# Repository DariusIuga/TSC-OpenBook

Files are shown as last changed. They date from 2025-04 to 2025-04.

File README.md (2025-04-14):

# TSC-OpenBook

An implementation of an open-source E-book reader made in Autodesk Fusion 360.

## Block Diagram
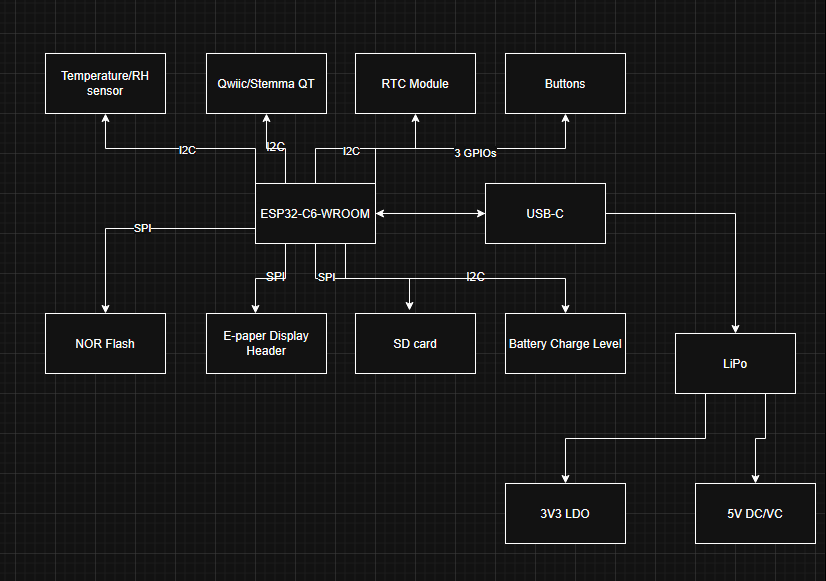
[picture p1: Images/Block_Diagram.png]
Diagram


## Enclosure
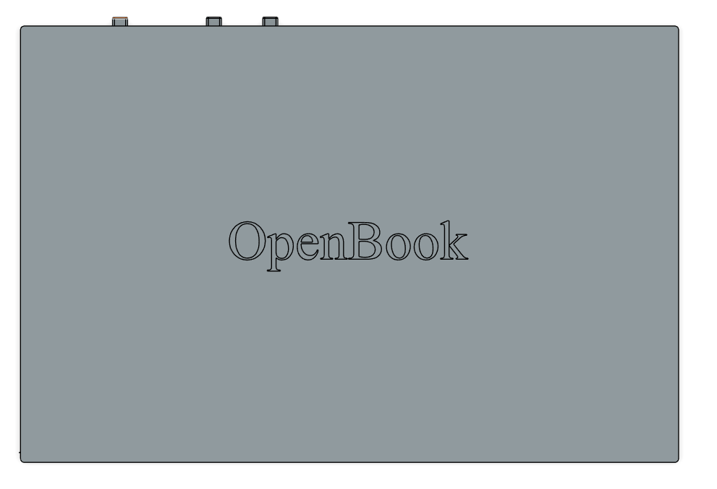
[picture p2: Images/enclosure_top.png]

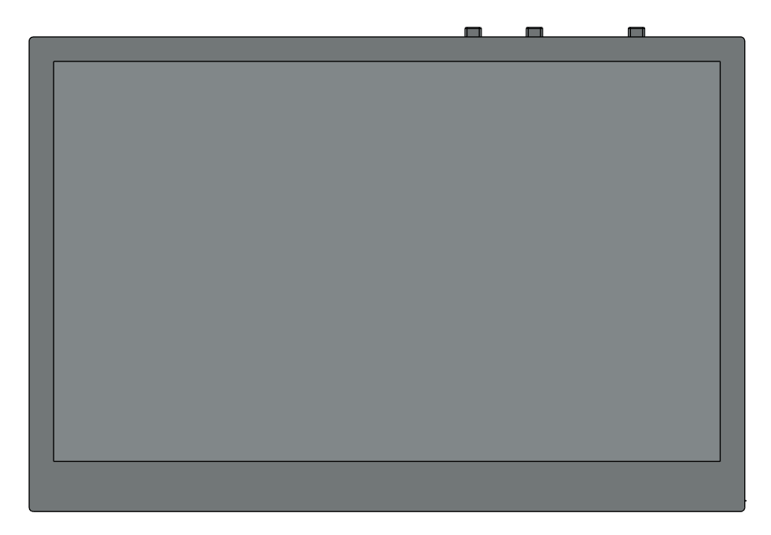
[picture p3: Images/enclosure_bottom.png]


## PCB
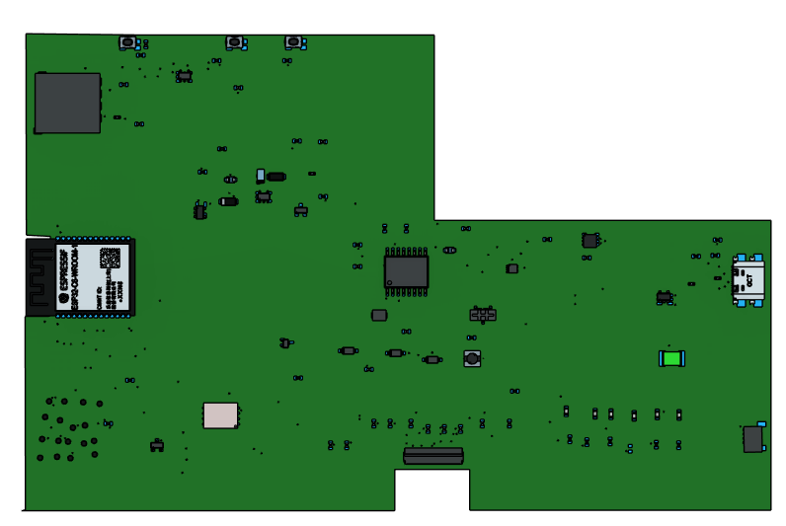
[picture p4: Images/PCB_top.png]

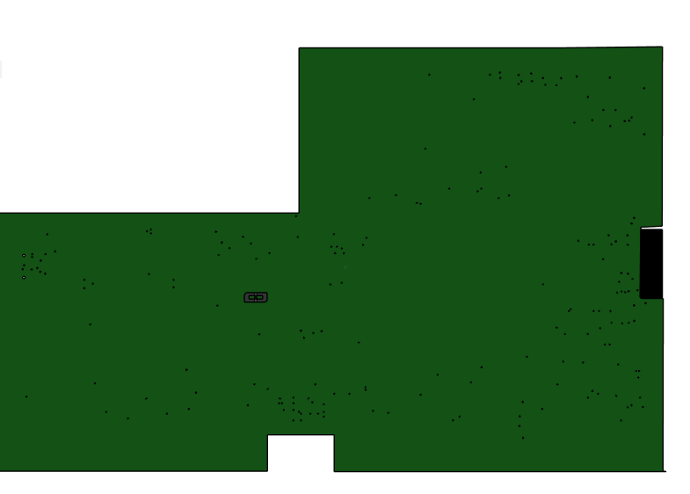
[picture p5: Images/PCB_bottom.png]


## Display

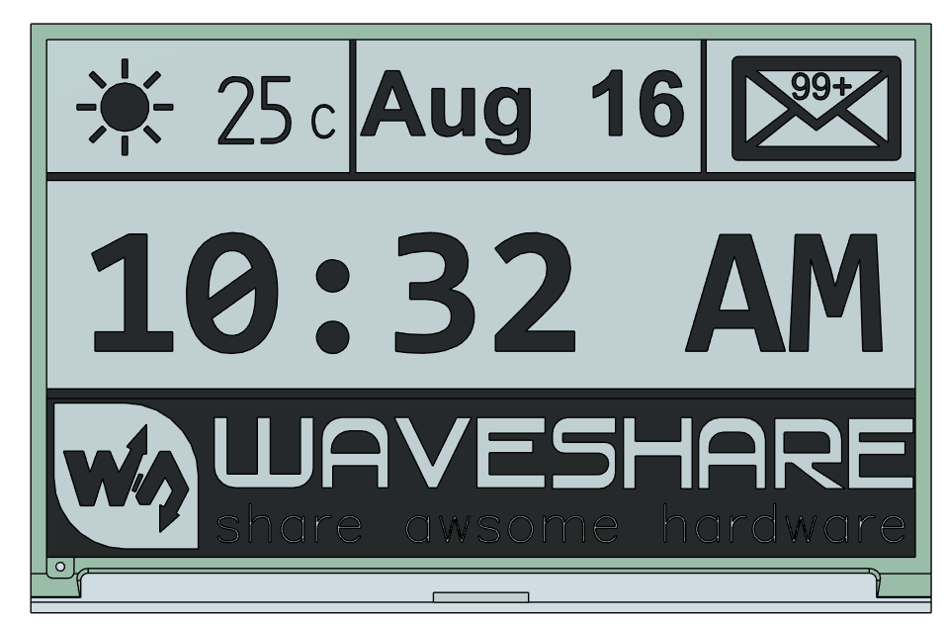
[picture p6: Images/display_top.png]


## Descrierea Funcționalității Hardware

Acest proiect utilizează modulul **ESP32-C6-WROOM-1-N8** ca unitate principală de microcontroler (MCU). Acest modul dispune de un nucleu RISC-V pe 32 de biți ce rulează până la 160MHz, conectivitate Wi-Fi 6 și Bluetooth 5 (BLE) integrate, 512KB SRAM și interfațează cu 8MB de memorie flash NOR externă (W25Q64JV / W25Q512JVEIQ) prin SPI pentru stocarea firmware-ului.

**Componente Cheie și Interfețe:**

* **Afișaj:** Un display E-Paper (EPD) alb-negru de 7.5 inci, cu rezoluție 800x480 pixeli, este utilizat ca ieșire vizuală principală. Acesta se conectează la ESP32-C6 printr-o interfață SPI cu 4 fire, suplimentată de pini dedicați pentru reset (RST), selecție dată/comandă (DC), selecție cip (CS) și indicarea stării de ocupat (BUSY).
* **Managementul Alimentării:**
    * Dispozitivul este alimentat de o baterie Litiu-Polimer de 3.7V, 2500mAh.
    * Încărcarea bateriei este gestionată de circuitul integrat **MCP73831**, acceptând alimentare prin portul USB-C. Un LED de stare indică starea încărcării.
    * Circuitul integrat **MAX17048** acționează ca un indicator al nivelului bateriei (fuel gauge), monitorizând starea de încărcare a bateriei și comunicând această informație către MCU prin magistrala I2C.
    * Un regulator Low-Dropout (LDO) **XC6220A331MR-G** convertește tensiunea bateriei sau tensiunea USB (VBUS) la tensiunea stabilă de 3.3V necesară componentelor sistemului.
    * Un supervizor de tensiune **BD5229G-TR** monitorizează magistrala de 3.3V și menține ESP32-C6 în reset dacă tensiunea scade sub un prag sigur, asigurând stabilitatea sistemului.
* **Senzori de Mediu:** Un senzor **BME688** (sau BME680 conform BOM) este inclus pentru a măsura temperatura, umiditatea, presiunea barometrică și compușii organici volatili (VOC) pentru estimarea calității aerului. Acesta comunică cu ESP32-C6 prin magistrala I2C. *(Notă: Cerințele specifică BME688, BOM listează BME680. Funcționalitatea e similară, dar BME688 are capabilități AI îmbunătățite)*
* **Ceas de Timp Real (RTC):** Un modul RTC **DS3231SN** oferă măsurare precisă a timpului, chiar și atunci când MCU-ul principal este într-o stare de consum redus. Include un supercondensator de backup (**CPH3225A**) și comunică prin magistrala I2C.
* **Stocare:** Pe lângă memoria flash SPI externă pentru firmware (**W25Q512JVEIQ** - 64MByte), este prevăzut un slot pentru card MicroSD (**112A-TAAR-R03**) pentru stocarea datelor utilizatorului (ex. cărți electronice). Acesta interfațează cu ESP32-C6 folosind protocolul SDIO (sau SPI).
* **Interfață Utilizator:** Trei butoane tactile sunt disponibile pentru interacțiunea cu utilizatorul:
    * Buton Reset: Declanșează direct resetarea sistemului prin pinul EN (prin intermediul supervizorului de tensiune).
    * Buton Boot (GPIO0): Folosit pentru a plasa manual ESP32-C6 în modul de programare/bootloader la resetare.
    * Buton Change (GPIO21): Un buton de uz general pentru funcții specifice aplicației (ex. întoarcerea paginii, navigare în meniu).
* **Conectivitate & Depanare:**
    * Un port **USB-C** (**USB4110-GF-A**) oferă alimentare pentru încărcare și o interfață USB 2.0 Full-Speed pentru transfer de date și programare/depanare prin controlerul USB Serial/JTAG nativ al ESP32-C6. Protecție ESD (**USBLC6-2SC6Y**) este inclusă pe liniile USB.
    * Un conector **Qwiic/Stemma QT** (nepopulat în schemă, dar pinii I2C sunt disponibili pe J5) oferă o modalitate ușoară de a conecta periferice I2C suplimentare.
    * Pad-urile de test expun semnale cheie precum UART (TXD, RXD), SPI (pentru Flash și Card SD) și I2C în scopuri de depanare și testare.

## Utilizarea Pinilor ESP32-C6

Următorul tabel detaliază pinii GPIO specifici utilizați pe modulul ESP32-C6-WROOM-1 și funcțiile acestora în cadrul acestui proiect:

| Pin ESP32-C6 | Funcție | Component(e) Conectat(e) | Interfață/Motiv |
| :--- | :--- | :--- | :--- |
| GPIO0 | Selecție Boot / Intrare Buton | SW_BOOT (Buton Boot), R_BOOT | Pin standard pentru selecția modului boot; Intrare utilizator |
| GPIO1 | Ceas I2C | U4 (MAX17048), U3 (DS3231), SENSOR2 (BME68x), J5 (Qwiic) | Magistrală I2C comună (SCL) pentru multipli senzori/CI |
| GPIO2 | Date I2C | U4 (MAX17048), U3 (DS3231), SENSOR2 (BME68x), J5 (Qwiic) | Magistrală I2C comună (SDA) pentru multipli senzori/CI |
| GPIO3 | Selecție Cip E-Paper | J1 (Header EPD) | Selecție Cip SPI (CS) pentru Afișajul E-Paper |
| GPIO4 | Dată/Comandă E-Paper | J1 (Header EPD) | Control Dată/Comandă (DC) pentru Afișajul E-Paper |
| GPIO5 | Reset E-Paper | J1 (Header EPD) | Semnal Reset (RST) pentru Afișajul E-Paper |
| GPIO6 | Stare Ocupat E-Paper | J1 (Header EPD) | Semnal intrare Ocupat (Busy) de la Afișajul E-Paper |
| GPIO7 | Hold Flash Extern | U1 (W25Q512JVEIQ), TP17 | Semnal SPI Hold (/HOLD) pentru memoria flash externă |
| GPIO8 | Dată 0 Card SD | J2 (Slot Card SD), TP6 | Linie Date SDIO 0 / SPI MISO |
| GPIO9 | Dată 1 Card SD | J2 (Slot Card SD), TP7 | Linie Date SDIO 1 |
| GPIO10 | Comandă Card SD | J2 (Slot Card SD), TP5 | Linie Comandă SDIO / SPI MOSI |
| GPIO11 | Ceas Card SD | J2 (Slot Card SD), TP4 | Linie Ceas SDIO / SPI SCK |
| GPIO12 | Protecție Scriere Flash Extern | U1 (W25Q512JVEIQ), TP16 | Semnal SPI Protecție Scriere (/WP) pentru flash extern |
| GPIO13 | MISO Flash Extern | U1 (W25Q512JVEIQ), TP15 | SPI Master In Slave Out (MISO) pentru flash extern |
| GPIO14 | MOSI Flash Extern | U1 (W25Q512JVEIQ), TP14 | SPI Master Out Slave In (MOSI) pentru flash extern |
| GPIO15 | Selecție Cip Flash Extern | U1 (W25Q512JVEIQ), TP13 | Selecție Cip SPI (/CS) pentru memoria flash externă |
| GPIO16 | UART TXD | TP12 | Date Transmise UART pentru depanare/programare |
| GPIO17 | UART RXD | TP11 | Date Recepționate UART pentru depanare/programare |
| GPIO18 | Ceas Flash Extern | U1 (W25Q512JVEIQ), TP3 | Ceas SPI (SCK) pentru memoria flash externă |
| GPIO19 | Dată 2 Card SD | J2 (Slot Card SD), TP8 | Linie Date SDIO 2 |
| GPIO20 | Dată 3 Card SD / Detectare Card | J2 (Slot Card SD), TP9 | Linie Date SDIO 3 / Intrare Detectare Card |
| GPIO21 | Intrare Buton Change | SW_CHANGE (Buton Change) | Intrare de Uz General pentru interacțiune utilizator |
| USB_D- | Date Negative USB | J4 (Conector USB-C) | Semnal Nativ USB D- |
| USB_D+ | Date Pozitive USB | J4 (Conector USB-C) | Semnal Nativ USB D+ |
| EN | Activare Sistem / Reset | U5 (BD5229G), SW_RESET (Buton Reset) | Activare Cip, controlat de supervizor tensiune/buton |

*Notă: Perifericele SPI partajate (cum ar fi afișajul E-Paper și potențial cardul SD în modul SPI) ar partaja în mod tipic liniile SCK, MOSI și MISO, necesitând pini CS dedicați pentru fiecare dispozitiv. Cu toate acestea, acest design folosește GPIO-uri separate pentru controlul EPD și interfețe dedicate (SDIO și SPI) pentru Cardul SD și respectiv Flash-ul Extern, conform mapării de mai sus.*

## Pași de Implementare

Procesul de dezvoltare a acestui proiect a urmat, în linii mari, următorii pași:

1.  **Analiza Cerințelor:** Înțelegerea documentelor de specificații (MRD, PRD, ERD) și a cerințelor hardware detaliate.
2.  **Selecția Componentelor:** Alegerea componentelor principale (ESP32-C6, display E-Paper 7.5", BME68x, MAX17048, MCP73831, DS3231SN, W25Q512JVEIQ etc.) pe baza cerințelor de funcționalitate, performanță, consum și cost.
3.  **Proiectarea Schematicii:** Crearea diagramelor electrice în Autodesk Fusion 360, interconectând componentele conform datasheet-urilor și logicii funcționale.
4.  **Design PCB (Layout):** Amplasarea componentelor pe placa de circuit imprimat, rutarea traseelor electrice respectând constrângerile (grosimi trasee de putere/semnal, izolare, reguli DRC/ERC).
5.  **Verificări Design:** Rularea verificărilor ERC (Electrical Rule Check) și DRC (Design Rule Check) pentru a identifica potențiale probleme în schematică și layout.
6.  **Modelare 3D și Integrare Mecanică:** Crearea modelelor 3D pentru PCB-ul asamblat, baterie și display. Integrarea acestora în modelul 3D al carcasei furnizate pentru a verifica potrivirea mecanică și spațiul disponibil.
7.  **Generare Fișiere de Producție:** Crearea fișierelor Gerber pentru fabricarea PCB-ului, a listei de materiale (BOM - Bill of Materials) și a fișierului Pick and Place (CPL) pentru asamblarea automată.

## Estimare Consum Energie

Consumul de energie al dispozitivului variază semnificativ în funcție de modul de operare. Mai jos sunt estimări aproximative:

* **Mod Activ (Citire / Conectat Wi-Fi):**
    * ESP32-C6: ~80-150mA (poate crește semnificativ în timpul transmisiei active Wi-Fi/BT)
    * Display E-Paper: Neglijabil (µA) când imaginea este statică.
    * Senzori, RTC, Flash (citire ocazională): ~5-10mA în total.
    * **Total estimat:** **~90 - 170 mA** (fără refresh EPD)

* **Mod Refresh Display E-Paper:**
    * Display-ul consumă curent doar în timpul actualizării (aproximativ 1-2 secunde).
    * Consum EPD în refresh: ~20-40mA.
    * **Total estimat (în timpul refresh-ului):** Consumul modului activ + **~20-40mA**.

* **Mod Sleep (Deep Sleep):**
    * ESP32-C6: țintă < 50µA (tipic 10-25µA în deep sleep).
    * RTC (pe backup): ~1-2µA.
    * Fuel Gauge (MAX17048): ~5-10µA.
    * LDO (Quiescent current): ~1-5µA.
    * Scurgeri diverse: ~1-5µA.
    * **Total estimat:** **~20 - 50 µA**. Acest consum redus permite o durată de viață a bateriei foarte lungă în standby.

**Notă:** Aceste valori sunt estimative și depind în mare măsură de implementarea firmware și de caracteristicile specifice ale componentelor utilizate. 

## Considerente Design și Amplasare

**Selecția Componentelor:**

Alegerea componentelor s-a bazat pe cerințele hardware specificate, urmărind un echilibru între funcționalitate, consum redus de energie, disponibilitate și cost:

* **ESP32-C6:** Selectat pentru capabilitățile sale moderne Wi-Fi 6/BLE, nucleul RISC-V eficient energetic, suportul bun pentru moduri low-power și setul adecvat de periferice (SPI, I2C, SDIO, USB).
* **Display E-Paper 7.5":** Ideal pentru un e-reader datorită consumului zero în stare statică și lizibilității excelente în lumină ambientală. Interfața SPI este comună și ușor de implementat.
* **BME680/688:** Integrarea senzorilor de mediu într-un singur pachet compact (I2C).
* **MCP73831 & MAX17048:** O combinație standard și fiabilă pentru încărcarea și monitorizarea precisă a bateriei Li-Po.
* **DS3231SN:** Un RTC precis cu compensare de temperatură, esențial pentru funcții dependente de timp. Supercapacitorul elimină necesitatea unei baterii de backup separate pentru RTC.
* **W25Q512JVEIQ:** Oferă cei 8MB (64Mbit) de stocare flash externă necesari conform specificațiilor, folosind o interfață SPI standard.
* **Conectori (USB-C, SD Card, FFC):** Aleși pentru a corespunde standardelor actuale și cerințelor de conectivitate.

**Amplasarea Componentelor și Integrarea în Carcasă:**

Layout-ul PCB-ului și amplasarea componentelor au fost realizate ținând cont de constrângerile carcasei și de regulile de bună practică în designul electronic:

* **Potrivire Mecanică:** Forma PCB-ului a fost adaptată pentru a se potrivi în interiorul carcasei și a utiliza punctele de montaj existente.
* **Antena RF:** Modulul ESP32-C6 a fost plasat la marginea PCB-ului, cu antena orientată spre exterior. Zona de sub antenă a fost decupată din PCB și nu conține plan de masă sau trasee, conform recomandărilor Espressif, pentru a maximiza performanța radio.
* **Conectori Externi:** Portul USB-C și butoanele au fost poziționate pentru a corespunde decupajelor din carcasă.
* **Conector Display:** Conectorul FFC pentru display a fost plasat strategic pentru a facilita conectarea cablului flexibil al E-Paper-ului.
* **Amplasare Generală:** Componentele au fost plasate exclusiv pe stratul TOP, conform cerințelor. S-a urmărit o distribuție logică (ex: circuitul de încărcare lângă USB, senzorii grupați, memoria flash lângă MCU).
* **Condensatoare de Decuplare:** Au fost plasate cât mai aproape posibil de pinii de alimentare ai circuitelor integrate (ESP32, BME68x, MAX17048 etc.) pentru a asigura stabilitatea alimentării.
* **Baterie:** Spațiul principal din interiorul carcasei a fost alocat pentru bateria Li-Po, care se conectează direct la pad-uri de pe PCB.

## Bill of Materials (BOM)

| Component | Description | Datasheet | Shop - Mouser |
|---|---|---|---|
| ESP32-C6-WROOM-1-N8 | Wi-Fi, BLE, Zigbee SoC Module | [Datasheet](https://www.espressif.com/sites/default/files/documentation/esp32-c6-wroom-1_wroom-1u_datasheet_en.pdf) | [Shop](https://eu.mouser.com/ProductDetail/Espressif-Systems/ESP32-C6-WROOM-1U-N8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) |
| MCP73831 | Li-Po Battery Charging Controller | [Datasheet](https://eu.mouser.com/datasheet/2/268/MCP73831_Family_Data_Sheet_DS20001984H-3441711.pdf) | [Shop](https://eu.mouser.com/ProductDetail/Microchip-Technology/MCP73831T-2ACI-OT?qs=yUQqVecv4qvbBQBGbHx0Mw%3D%3D) |
| XC6220A331MR-G | LDO Voltage Regulator | [Datasheet](https://eu.mouser.com/datasheet/2/760/xc6220-3371556.pdf) | [Shop](https://eu.mouser.com/ProductDetail/Torex-Semiconductor/XC6220A331MR-G?qs=AsjdqWjXhJ8ZSWznL1J0gg%3D%3D) |
| BME680 | Environmental Sensor | [Datasheet](https://eu.mouser.com/datasheet/2/783/BST_BME680_DS001-1509608.pdf) | [Shop](https://eu.mouser.com/ProductDetail/Bosch-Sensortec/BME680?qs=v271MhAjFHjo0yA%2FC4OnDQ%3D%3D) |
| DS3231SN | Real-Time Clock | [Datasheet](https://eu.mouser.com/datasheet/2/609/DS3231-3421123.pdf) | [Shop](https://eu.mouser.com/ProductDetail/Analog-Devices-Maxim-Integrated/DS3231SN?qs=1eQvB6Dk1vhUlr8%2FOrV0Fw%3D%3D) |
| W25Q512JVEIQ | 512Mb (64MB) Flash Memory | [Datasheet](https://eu.mouser.com/datasheet/2/949/Winbond_W25Q512JV_Datasheet-3240039.pdf) | [Shop](https://eu.mouser.com/ProductDetail/Winbond/W25Q512JVEIQ?qs=l7cgNqFNU1jw6svr3at6tA%3D%3D) |
| MAX17048G+T10 | Battery Fuel Gauge | [Datasheet](https://eu.mouser.com/datasheet/2/609/MAX17048_MAX17049-3469099.pdf) | [Shop](https://eu.mouser.com/ProductDetail/Analog-Devices-Maxim-Integrated/MAX17048G%2bT10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) |
| SI1308EDL-T1-GE3 | N-Channel MOSFET | [Datasheet](https://www.vishay.com/docs/63399/si1308edl.pdf) | [Shop](https://eu.mouser.com/ProductDetail/Vishay-Semiconductors/SI1308EDL-T1-GE3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) |
| DMG2305UX-7 | P-Channel MOSFET | [Datasheet](https://www.diodes.com/assets/Datasheets/DMG2305UX.pdf) | [Shop](https://eu.mouser.com/ProductDetail/Diodes-Incorporated/DMG2305UX-7?qs=L1DZKBg7t5F%2FNBHrjfxC%252Bg%3D%3D) |
| USBLC6-2SC6Y | USB ESD Protection | [Datasheet](https://eu.mouser.com/datasheet/2/389/usblc6_2sc6y-1852505.pdf) | [Shop](https://eu.mouser.com/ProductDetail/STMicroelectronics/USBLC6-2SC6Y?qs=gNDSiZmRJS%2FOgDexvXkdow%3D%3D) |
| USB4110-GF-A | USB Type-C Connector | [Datasheet](https://eu.mouser.com/datasheet/2/837/GCT_USB4110_Product_Drawing___20k_cycles-3455479.pdf) | [Shop](https://eu.mouser.com/ProductDetail/GCT/USB4110-GF-A?qs=KUoIvG%2F9IlYiZvIXQjyJeA%3D%3D) |
| 112A-TAAR-R03 | Micro SD Card Connector | [Datasheet](https://www.attend.com.tw/data/download/file/112A-TAAR-R03_Spec.pdf) | [Shop](https://www.tme.eu/ro/details/mcc-sdmicro/conectori-pentru-cartele/attend/112a-taar-r03/) |
| Waveshare Display | 7.5" E-Ink | [Datasheet](https://files.waveshare.com/upload/6/60/7.5inch_e-Paper_V2_Specification.pdf) | [Shop](https://www.waveshare.com/7.5inch-e-paper-hat.htm) |
| CPH3225A | 11mF Supercapacitor | [Datasheet](https://eu.mouser.com/datasheet/2/360/Seiko_Instruments_MicroBattery_E_20230330_2024Jan_-3561061.pdf) | [Shop](https://eu.mouser.com/ProductDetail/Seiko-Semiconductors/CPH3225A?qs=3etwrb1wR%252BhUOph6lAO7eg%3D%3D) |
| BD5229G-TR | Voltage Supervisor | [Datasheet](https://eu.mouser.com/datasheet/2/348/bd52xxg_e-3421856.pdf) | [Shop](https://eu.mouser.com/ProductDetail/ROHM-Semiconductor/BD5229G-TR?qs=PVQ7ZECv46n5JbI7K86q0w%3D%3D) |

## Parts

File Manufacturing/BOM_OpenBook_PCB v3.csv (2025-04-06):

Qty | Value | Device | Package | Parts | Description | ARROW_PART_NUMBER | ARROW_PRICE-STOCK | AVAILABILITY | CATEGORY | CENTROID_NOT_SPECIFIED | CHECK_PRICES | COPYRIGHT | DATASHEET | DESCRIPTION | DIGIKEY_DESCRIPTION | DIGIKEY_PART_NUMBER | HEIGHT | LEAD_FREE | MANUFACTURER | MANUFACTURER_NAME | MANUFACTURER_PART_NUMBER | MF | MFR_NAME | MOUSER_PART_NUMBER | MOUSER_PRICE-STOCK | MP | MPN | OPERATING_TEMPERATURE | PACKAGE | PACKAGE_SIZE | PACKAGE_TYPE | PART_STATUS | POPULARITY | PREFIX | PRICE | PROD_ID | PURCHASE-URL | ROHS | SERIES | SNAPEDA_LINK | SPICEMODEL | SPICEPREFIX | SUBCATEGORY | TEMPERATURE_RANGE_HIGH | TEMPERATURE_RANGE_LOW | THERMALLOSS | TOLERANCE | TP_SIGNAL_NAME | TYPE | VALUE | VOLTAGE_RATING
1 |  | ADAFRUIT_LEDCHIP-LED0603 | ADAFRUIT_CHIP-LED0603 | CHG_LED | LED
1 |  | SJ | SJ | SJ1 | SMD solder JUMPER |  |  |  |  |  |  |  |  |  |  |  |  |  |  |  |  |  |  |  |  |  |  |  |  |  |  |  | 3
1 | 0.1uF/50V | ESP32_WROVER_EAGLE-LTSPICE_CC0402 | ESP32_WROVER_EAGLE-LTSPICE_C0402 | EPD_C5 | CAPACITOR, European symbol |  |  |  |  |  |  |  |  |  |  |  |  |  |  |  |  |  |  |  |  |  |  |  |  |  |  |  |  |  |  |  |  |  |  |  | NONE | C
1 | 0.47 | ESP32_WROVER_EAGLE-LTSPICE_RR0402 | ESP32_WROVER_EAGLE-LTSPICE_R0402 | R3 | RESISTOR, European symbol |  |  |  |  |  |  |  |  |  |  |  |  |  |  |  |  |  |  |  |  |  |  |  |  |  |  |  |  |  |  |  |  |  |  |  | NONE | R
1 | 100k | ESP32_WROVER_EAGLE-LTSPICE_RR0402 | ESP32_WROVER_EAGLE-LTSPICE_R0402 | R1_PWUSB | RESISTOR, European symbol |  |  |  |  |  |  |  |  |  |  |  |  |  |  |  |  |  |  |  |  |  |  |  |  |  |  |  |  |  |  |  |  |  |  |  | NONE | R
2 | 100nF | C_CHIP-0402(1005-METRIC) | CAPC1005X60 | C4_USB, C9 | Capacitor - Generic |  |  |  | Capacitor |  |  |  |  |  |  |  |  |  |  |  |  |  |  |  |  |  |  |  |  | 0402 | SMD |  |  |  |  |  |  |  |  |  |  |  | Ceramic Capacitors |  |  |  |  |  | MLCC
1 | 100nF | EAGLE-LTSPICE_CC0402 | EAGLE-LTSPICE_C0402 | C8 | CAPACITOR, European symbol |  |  |  |  |  |  |  |  |  |  |  |  |  |  |  |  |  |  |  |  |  |  |  |  |  |  |  |  |  |  |  |  |  |  |  | NONE | C
5 | 100nF | ESP32_WROVER_EAGLE-LTSPICE_CC0402 | ESP32_WROVER_EAGLE-LTSPICE_C0402 | C1, C2, C6, C10, C_DELAY | CAPACITOR, European symbol |  |  |  |  |  |  |  |  |  |  |  |  |  |  |  |  |  |  |  |  |  |  |  |  |  |  |  |  |  |  |  |  |  |  |  | NONE | C
1 | 100uF TANT | C-POL_TANTALUM-1206(3216-METRIC) | CAPMP3216X180N | C3 | Capacitor Polarised - Generic |  |  |  | Capacitor |  |  |  |  |  |  |  |  |  |  |  |  |  |  |  |  |  |  |  |  | 1206 | SMD |  |  |  |  |  |  |  |  |  |  |  | Tantalum Capacitors |  |  |  |  |  | Polymer Capacitors
16 | 10k | ESP32_WROVER_EAGLE-LTSPICE_RR0402 | ESP32_WROVER_EAGLE-LTSPICE_R0402 | R1, R1_PINH, R1_PINH1, R2-PINH, R2-PINH1, R4, R5, R6, R7, R8, R9, R10, R_BOOT, R_CHANGE, R_CL1, R_RESET | RESISTOR, European symbol |  |  |  |  |  |  |  |  |  |  |  |  |  |  |  |  |  |  |  |  |  |  |  |  |  |  |  |  |  |  |  |  |  |  |  | NONE | R
1 | 10uF | EAGLE-LTSPICE_CC0402 | EAGLE-LTSPICE_C0402 | C7 | CAPACITOR, European symbol |  |  |  |  |  |  |  |  |  |  |  |  |  |  |  |  |  |  |  |  |  |  |  |  |  |  |  |  |  |  |  |  |  |  |  | NONE | C
1 | 112A-TAAR-R03_ATTEND | 112A-TAAR-R03_ATTEND | 112ATAARR03ATTEND | J4 | Micro SD Card Socket, Push-Push Type, Top Mount, SMT, H=1.83mm, 10u |  |  |  |  |  |  |  |  | Micro SD Card Socket | Push-Push Type | Top Mount | SMT | H=1.83mm | 10u |  |  | 1.9mm |  |  | ATTEND | 112A-TAAR-R03 ATTEND
1 | 15 | ESP32_WROVER_EAGLE-LTSPICE_RR0402 | ESP32_WROVER_EAGLE-LTSPICE_R0402 | R_CAPACITOR | RESISTOR, European symbol |  |  |  |  |  |  |  |  |  |  |  |  |  |  |  |  |  |  |  |  |  |  |  |  |  |  |  |  |  |  |  |  |  |  |  | NONE | R
1 | 1uF | ESP32_WROVER_EAGLE-LTSPICE_CC0402 | ESP32_WROVER_EAGLE-LTSPICE_C0402 | C5 | CAPACITOR, European symbol |  |  |  |  |  |  |  |  |  |  |  |  |  |  |  |  |  |  |  |  |  |  |  |  |  |  |  |  |  |  |  |  |  |  |  | NONE | C
9 | 1uF/50V | ESP32_WROVER_EAGLE-LTSPICE_CC0402 | ESP32_WROVER_EAGLE-LTSPICE_C0402 | EPD_C1, EPD_C2, EPD_C6, EPD_C7, EPD_C8, EPD_C9, EPD_C10, EPD_C11, EPD_C12 | CAPACITOR, European symbol |  |  |  |  |  |  |  |  |  |  |  |  |  |  |  |  |  |  |  |  |  |  |  |  |  |  |  |  |  |  |  |  |  |  |  | NONE | C
1 | 2.2 | ESP32_WROVER_EAGLE-LTSPICE_RR0402 | ESP32_WROVER_EAGLE-LTSPICE_R0402 | R2 | RESISTOR, European symbol |  |  |  |  |  |  |  |  |  |  |  |  |  |  |  |  |  |  |  |  |  |  |  |  |  |  |  |  |  |  |  |  |  |  |  | NONE | R
1 | 200 | ESP32_WROVER_EAGLE-LTSPICE_RR0402 | ESP32_WROVER_EAGLE-LTSPICE_R0402 | R1_BAT | RESISTOR, European symbol |  |  |  |  |  |  |  |  |  |  |  |  |  |  |  |  |  |  |  |  |  |  |  |  |  |  |  |  |  |  |  |  |  |  |  | NONE | R
2 | 20V/4.2A/52mO/1.4W | ESP32_WROVER_SPARKFUN-DISCRETESEMI_MOSFET_PCH-DMG2305UX-7 | ESP32_WROVER_SPARKFUN-DISCRETESEMI_SOT23-3 | Q1, Q2 | P-channel MOSFETs |  |  |  |  |  |  |  |  |  |  |  |  |  |  |  |  |  |  |  |  |  |  |  |  |  |  |  |  |  |  | TRAN-14388 |  |  |  |  |  |  |  |  |  |  |  |  |  | 20V/4.2A/52mO/1.4W
1 | 2k | ESP32_WROVER_EAGLE-LTSPICE_RR0402 | ESP32_WROVER_EAGLE-LTSPICE_R0402 | R2_BAT | RESISTOR, European symbol |  |  |  |  |  |  |  |  |  |  |  |  |  |  |  |  |  |  |  |  |  |  |  |  |  |  |  |  |  |  |  |  |  |  |  | NONE | R
2 | 4.7uF | C_CHIP-0402(1005-METRIC) | CAPC1005X60 | C1_BAT1, C5_USB | Capacitor - Generic |  |  |  | Capacitor |  |  |  |  |  |  |  |  |  |  |  |  |  |  |  |  |  |  |  |  | 0402 | SMD |  |  |  |  |  |  |  |  |  |  |  | Ceramic Capacitors |  |  |  |  |  | MLCC
1 | 4.7uF | C_TANTALUM-1206(3216-METRIC) | CAPM3216X180 | C1_BAT2 | Capacitor - Generic |  |  |  | Capacitor |  |  |  |  |  |  |  |  |  |  |  |  |  |  |  |  |  |  |  |  | 1206 | SMD |  |  |  |  |  |  |  |  |  |  |  | Tantalum Capacitors |  |  |  |  |  | Polymer Capacitors
2 | 4.7uF | ESP32_WROVER_EAGLE-LTSPICE_CC0402 | ESP32_WROVER_EAGLE-LTSPICE_C0402 | C1_BAT, C2_BAT | CAPACITOR, European symbol |  |  |  |  |  |  |  |  |  |  |  |  |  |  |  |  |  |  |  |  |  |  |  |  |  |  |  |  |  |  |  |  |  |  |  | NONE | C
1 | 4.7uF/25V | EAGLE-LTSPICE_CC0402 | EAGLE-LTSPICE_C0402 | C4 | CAPACITOR, European symbol |  |  |  |  |  |  |  |  |  |  |  |  |  |  |  |  |  |  |  |  |  |  |  |  |  |  |  |  |  |  |  |  |  |  |  | NONE | C
2 | 5k1 | ESP32_WROVER_EAGLE-LTSPICE_RR0402 | ESP32_WROVER_EAGLE-LTSPICE_R0402 | R2-USB, R2-USB1 | RESISTOR, European symbol |  |  |  |  |  |  |  |  |  |  |  |  |  |  |  |  |  |  |  |  |  |  |  |  |  |  |  |  |  |  |  |  |  |  |  | NONE | R
1 | 68uH | 744043680IND_4828-WE-TPC_WRE | IND_4828-WE-TPC_WRE | L1 |  |  |  |  |  |  |  | Copyright (C) 2024 Ultra Librarian. All rights reserved. |  |  |  |  |  |  |  |  | 744043680 |  | Wurth Electronics
1 | BD5229G-TR | BD5229G-TR | SOT95P280X125-5N | IC5 | Voltage Detector with Adjustable Delay Time: CMOS processes are utilized to develop high precision, low current consumption CMOS reset ICs that allow arbitrary setting of the delay time. The extensive lineup includes both Nch Open Drain and CMOS output types in a wide range of detection voltages (from 2.3V to 6.0V, in 0.1V steps), enabling selection of the ideal solution based on customer requirements. In addition, the entire series is of course both lead-free and RoHS-compliant. |  |  |  |  |  |  |  |  | Voltage Detector with Adjustable Delay Time: CMOS processes are utilized to develop high precision | low current consumption CMOS reset ICs that allow arbitrary setting of the delay time. The extensive lineup includes both Nch Open Drain and CMOS output types in a wide range of detection voltages (from 2.3V to 6.0V | in 0.1V steps) | enabling selection of the ideal solution based on customer requirements. In addition | the entire series is of course both lead-free and RoHS-compliant. |  |  | 1.25mm |  |  | ROHM Semiconductor | BD5229G-TR |  |  | 755-BD5229G-TR | https://www.mouser.co.uk/ProductDetail/ROHM-Semiconductor/BD5229G-TR?qs=4kLU8WoGk0vvnhrrYwdszw%3D%3D
3 | BUTTON_CUSYOMV1 | BUTTON_CUSYOMV1 | MYBUTTON | BOOT_BUTTON, CHANGE_BUTTON, RESET_BUTTON
1 | CPH3225A | CPH3225A | CAPCP3225X100N | C10_SUPERCAP | Cap 0.011F 3.3V 1210 Flat Check availability |  |  | Not in stock |  |  | https://www.snapeda.com/parts/CPH3225A/Seiko+Instruments/view-part/?ref=eda |  |  | 11 mF (EDLC) Supercapacitor 3.3 V 1210 (3225 Metric) - - |  |  |  |  |  |  |  | Seiko Instruments |  |  |  | CPH3225A |  |  | 1210 Seiko |  |  |  |  |  | None |  | https://www.snapeda.com/api/url_track_click_mouser/?unipart_id=562593&manufacturer=Seiko Instruments&part_name=CPH3225A&search_term=None |  |  | https://www.snapeda.com/parts/CPH3225A/Seiko+Instruments/view-part/?ref=snap
1 | DS3231SN# | DS3231SN# | SOIC127P1032X265-16N | U3 | Real Time Clock Serial 16-Pin SOIC W T/R Check availability |  |  | In Stock |  |  | https://www.snapeda.com/parts/DS3231SN%23/Analog+Devices/view-part/?ref=eda |  |  | Extremely Accurate I²C-Integrated RTC/TCXO/Crystal |  |  |  |  |  |  |  | Analog Devices |  |  |  | DS3231SN# |  |  | SOIC-16 Maxim |  |  |  |  |  | None |  | https://www.snapeda.com/api/url_track_click_mouser/?unipart_id=99048&manufacturer=Analog Devices&part_name=DS3231SN#&search_term=None |  |  | https://www.snapeda.com/parts/DS3231SN%23/Analog+Devices/view-part/?ref=snap
1 | ESP32-C6-WROOM-1-N8 | ESP32-C6-WROOM-1-N8 | XCVR_ESP32-C6-WROOM-1-N8 | U2 | Check availability |  |  | In Stock |  |  | https://www.snapeda.com/parts/ESP32-C6-WROOM-1-N8/Espressif+Systems/view-part/?ref=eda |  |  | Multiprotocol Modules ESP32-C6 module | Wi-Fi 6 in 2.4 GHz band | Bluetooth 5 | Zigbee 3.0 and Thread. ESP34-WROOM Compatible - ENGINEERING SAMPLE |  |  |  |  |  |  |  | Espressif Systems |  |  |  | ESP32-C6-WROOM-1-N8 |  |  | None |  |  |  |  |  | None |  |  |  |  | https://www.snapeda.com/parts/ESP32-C6-WROOM-1-N8/Espressif+Systems/view-part/?ref=snap
1 | ESP32C6_VARISTORCN1812 | ESP32C6_VARISTORCN1812 | ESP32C6_VARISTOR_CT/CN1812 | PFMF.050.1 | VARISTOR |  |  |  |  |  |  |  |  |  |  |  |  |  |  |  |  |  |  |  |  |  |  |  |  |  |  |  | 0
2 | ESP32_WROVER_AVX---SD0805S020S1R0_AVX_SD0805S020S1R0_0_0AVX_SD0805S020S1R0_0_0 | ESP32_WROVER_AVX---SD0805S020S1R0_AVX_SD0805S020S1R0_0_0AVX_SD0805S020S1R0_0_0 | ESP32_WROVER_AVX---SD0805S020S1R0_AVX_SD0805S020S1R0_0 | D2, D7 | Schottky Barrier Rectifier Diode |  |  |  |  | No |  |  | http://datasheets.avx.com/schottky.pdf |  | DIODE SCHOTTKY 20V 1A 0805 | 478-7800-1-ND |  | yes |  |  |  | AVX |  | 581-SD0805S020S1R0 |  |  |  |  | 0805 (2012 metric) |  |  |  |  | D |  |  |  | yes |  |  |  |  |  | +125°C | -55°C
1 | ESP32_WROVER_BME680_BME680 | ESP32_WROVER_BME680_BME680 | ESP32_WROVER_BME680_PSON80P300X300X100-8N | SENSOR2 | Integrated Environmental Unit |  |  | Unavailable |  |  |  |  |  | Integrated Environmental Unit |  |  |  |  |  |  |  | Bosch Sensortec |  |  |  | BME680 |  |  | LGA-8 Bosch Tools |  |  |  |  |  | None
1 | ESP32_WROVER_SPARKFUN-IC-POWER_MCP73831 | ESP32_WROVER_SPARKFUN-IC-POWER_MCP73831 | ESP32_WROVER_SPARKFUN-IC-POWER_SOT23-5 | MCP73831 | MCP73831T Li-Ion, Li-Pol Controller |  |  |  |  |  |  |  |  |  |  |  |  |  |  |  |  |  |  |  |  |  |  |  |  |  |  |  |  |  |  | IC-09995
1 | FH34SRJ-24S-0.5SH_99_ | FH34SRJ-24S-0.5SH_99_ | FH34SRJ24S05SH99 | J1 | (0.50mm) Surface Mount, Right Angle |  |  |  |  |  |  |  |  | 24 Position FFC | FPC Connector Contacts | (0.50mm) Surface Mount | Right Angle |  |  | 1.1mm |  |  | Hirose | FH34SRJ-24S-0.5SH(99) |  |  | 798-FH34SRJ24S05SH99 | https://www.mouser.co.uk/ProductDetail/Hirose-Connector/FH34SRJ-24S-0.5SH99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
1 | MAX17048G+T10 | MAX17048G+T10 | SON50P200X200X80-9N | U4 | Check availability |  |  | In Stock |  |  | https://www.snapeda.com/parts/MAX17048G+T10/Analog+Devices/view-part/?ref=eda |  |  | 3µA 1-Cell/2-Cell Fuel Gauge with ModelGauge |  |  |  |  |  |  |  | Analog Devices |  |  |  | MAX17048G+T10 |  |  | TDFN-8 Maxim |  |  |  |  |  | None |  | https://www.snapeda.com/api/url_track_click_mouser/?unipart_id=329239&manufacturer=Analog Devices&part_name=MAX17048G+T10&search_term=None |  |  | https://www.snapeda.com/parts/MAX17048G+T10/Analog+Devices/view-part/?ref=snap
3 | MBR0530 | MBR0530 | SOD3716X135N | D3, D4, D5 | ON SEMICONDUCTOR - MBR0530 - DIODE, SCHOTTKY, 0.5A, 30V, SOD-123 |  |  | In Stock |  |  | https://www.snapeda.com/parts/MBR0530/Onsemi/view-part/?ref=eda |  |  | Diode Schottky 30 V 500mA Surface Mount SOD-123 |  |  |  |  |  |  |  | ON Semiconductor |  |  |  | MBR0530 |  |  | SOD-123-2 ON Semiconductor |  |  |  |  |  | None |  | https://www.snapeda.com/api/url_track_click_mouser/?unipart_id=179458&manufacturer=ON Semiconductor&part_name=MBR0530&search_term=None |  |  | https://www.snapeda.com/parts/MBR0530/Onsemi/view-part/?ref=snap
6 | PGB1010603MR | PGB1010603MR | DIOC1608X36N | D6, D8, D9, D10, D11, D12 | Check availability |  |  | In Stock |  |  | https://www.snapeda.com/parts/PGB1010603MR/Littelfuse/view-part/?ref=eda |  |  | 150V (Typ) Clamp - Ipp Tvs Diode Surface Mount 0603 (1608 Metric) |  |  |  |  |  |  |  | Littelfuse Inc. |  |  |  | PGB1010603MR |  |  | 0603 Littelfuse Inc. |  |  |  |  |  | None |  | https://www.snapeda.com/api/url_track_click_mouser/?unipart_id=5659453&manufacturer=Littelfuse Inc.&part_name=PGB1010603MR&search_term=None |  |  | https://www.snapeda.com/parts/PGB1010603MR/Littelfuse/view-part/?ref=snap
1 | QWIIC_RIGHT_ANGLE | QWIIC_CONNECTORJS-1MM | JST04_1MM_RA | J3 | SparkFun I2C Standard Qwiic Connector |  |  |  |  |  |  |  |  |  |  |  |  |  |  |  |  |  |  |  |  |  |  |  |  |  |  |  |  |  |  | CONN-13694 |  |  |  |  |  |  |  |  |  |  |  |  |  | QWIIC_RIGHT_ANGLE
1 | SAMACSYS_PARTS_USB4110-GF-A | SAMACSYS_PARTS_USB4110-GF-A | SAMACSYS_PARTS_USB4110GFA | J2 | CONN USB 2.0 TYPE-C R/A SMT |  |  |  |  |  |  |  |  | CONN USB 2.0 TYPE-C R/A SMT |  |  | 3.26mm |  |  | GCT (GLOBAL CONNECTOR TECHNOLOGY) | USB4110-GF-A |  |  | 640-USB4110-GF-A | https://www.mouser.co.uk/ProductDetail/GCT/USB4110-GF-A?qs=KUoIvG%2F9IlYiZvIXQjyJeA%3D%3D
1 | SI1308EDL-T1-GE3 | SI1308EDL-T1-GE3 | SOT65P210X110-3N | Q3 | MOSFET N-Ch 30V 1.5A TrenchFET SC70 Vishay Si1308EDL-T1-GE3 N-channel MOSFET Transistor, 1.5 A, 30 V, 3-Pin SC-70 | SI1308EDL-T1-GE3 | https://www.arrow.com/en/products/si1308edl-t1-ge3/vishay?utm_currency=USD&region=nac |  |  |  |  |  |  | MOSFET N-Ch 30V 1.5A TrenchFET SC70 Vishay Si1308EDL-T1-GE3 N-channel MOSFET Transistor | 1.5 A | 30 V | 3-Pin SC-70 |  |  | 1.1mm |  |  | Vishay | Si1308EDL-T1-GE3 |  |  | 78-SI1308EDL-T1-GE3 | https://www.mouser.co.uk/ProductDetail/Vishay-Semiconductors/SI1308EDL-T1-GE3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
17 | TPB1,27 | TPB1,27 | B1,27 | TP1, TP2, TP3, TP4, TP5, TP6, TP7, TP8, TP9, TP10, TP11, TP12, TP13, TP14, TP15, TP16, TP17 | Test pad |  |  |  |  |  |  |  |  |  |  |  |  |  |  |  |  |  |  |  |  |  |  |  |  |  |  |  | 19
1 | USBLC6-2SC6Y | USBLC6-2SC6Y | SOT95P280X145-6N | D1 | Low Cap. ESD Protection Auto SOT-23-6 STMicroelectronics USBLC6-2SC6Y, Dual Uni-Directional TVS Diode Array, 6-Pin SOT-23 |  |  | In Stock |  |  | https://www.snapeda.com/parts/USBLC6-2SC6Y/STMicroelectronics/view-part/?ref=eda |  |  | 17V Clamp 5A (8/20µs) Ipp Tvs Diode Surface Mount SOT-23-6 |  |  |  |  |  |  |  | STMicroelectronics |  |  |  | USBLC6-2SC6Y |  |  | SOT-23-6 STMicroelectronics |  |  |  |  |  | None |  |  |  |  | https://www.snapeda.com/parts/USBLC6-2SC6Y/STMicroelectronics/view-part/?ref=snap
1 | W25Q512JVEIQ | W25Q512JVEIQ | SON127P600X800X80-9N | U1 | Check availability |  |  | In Stock |  |  | https://www.snapeda.com/parts/W25Q512JVEIQ/Winbond+Electronics/view-part/?ref=eda |  |  | FLASH - NOR Memory IC 512Mb (64M x 8) SPI - Quad I/O 133 MHz 8-WSON (8x6) |  |  |  |  |  |  |  | Winbond Electronics |  |  |  | W25Q512JVEIQ |  |  | Package |  |  |  |  |  | None |  |  |  |  | https://www.snapeda.com/parts/W25Q512JVEIQ/Winbond+Electronics/view-part/?ref=snap
1 | XC6220A331MR-G | XC6220A331MR-G | SOT95P280X120-5N | IC1 | LDO Voltage Regulators |  |  |  |  |  |  |  |  | LDO Voltage Regulators |  |  | 1.2mm |  |  | Torex | XC6220A331MR-G |  |  | 865-XC6220A331MR-G | https://www.mouser.co.uk/ProductDetail/Torex-Semiconductor/XC6220A331MR-G?qs=AsjdqWjXhJ8ZSWznL1J0gg%3D%3D

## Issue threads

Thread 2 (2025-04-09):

#2 Warning: „SUPPLY pin AGND overwritten with GND”

georgianailie109, 2025-04-09:
In schematic iti apar mai multe warning-uri de tip „SUPPLY pin AGND overwritten with GND”.
Te rog sa refaci/reconectezi firele manual, ca sa te asiguri ca nu sunt doar vizual conectate, ci si logic.
Foloseste ERC pentru verificare.

Closed 2025-04-14.

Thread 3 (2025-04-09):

#3 Warning „Supply pin VCC overwritten with 3V3”

georgianailie109, 2025-04-09:
In schematic iti apar warning-uri de tipul „Supply pin VCC overwritten with 3V3”.
Te rog sa le reconectezi/refaci. Foloseste ERC pentru a te verifica.

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

Closed 2025-04-14.

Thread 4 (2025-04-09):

#4 Warning „Net PREVGH overlaps pin”

georgianailie109, 2025-04-09:
Apare un warning pentru ca netul PREVGH se suprapune cu un pin, dar nu e corect conectat.
Ar trebui mutat sau refacut traseul ca sa nu se mai suprapuna direct peste pin.

Closed 2025-04-14.

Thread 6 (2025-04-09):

#6 Componente 3D care nu sunt orientate corect

georgianailie109, 2025-04-09:
Unele componente din modelul 3D par puse invers sau intr-o pozitie putin deplasata fata de cum ar trebui montate pe PCB.
Ar fi bine sa verifici orientarea si sa le rotesti/ muti pentru a fi in pozitia corecta.

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

Closed 2025-04-14.

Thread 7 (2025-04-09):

#7 Lipsa decupaj conform modelului din enunt

georgianailie109, 2025-04-09:
In PCB si 3D nu apare decupajul din partea de sus a carcasei, prezent in modelul de referinta din enunt.
Ar trebui adaugat pentru ca butoanele sa se alinieze corect si sa fie accesibile prin carcasa.

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

Closed 2025-04-15.

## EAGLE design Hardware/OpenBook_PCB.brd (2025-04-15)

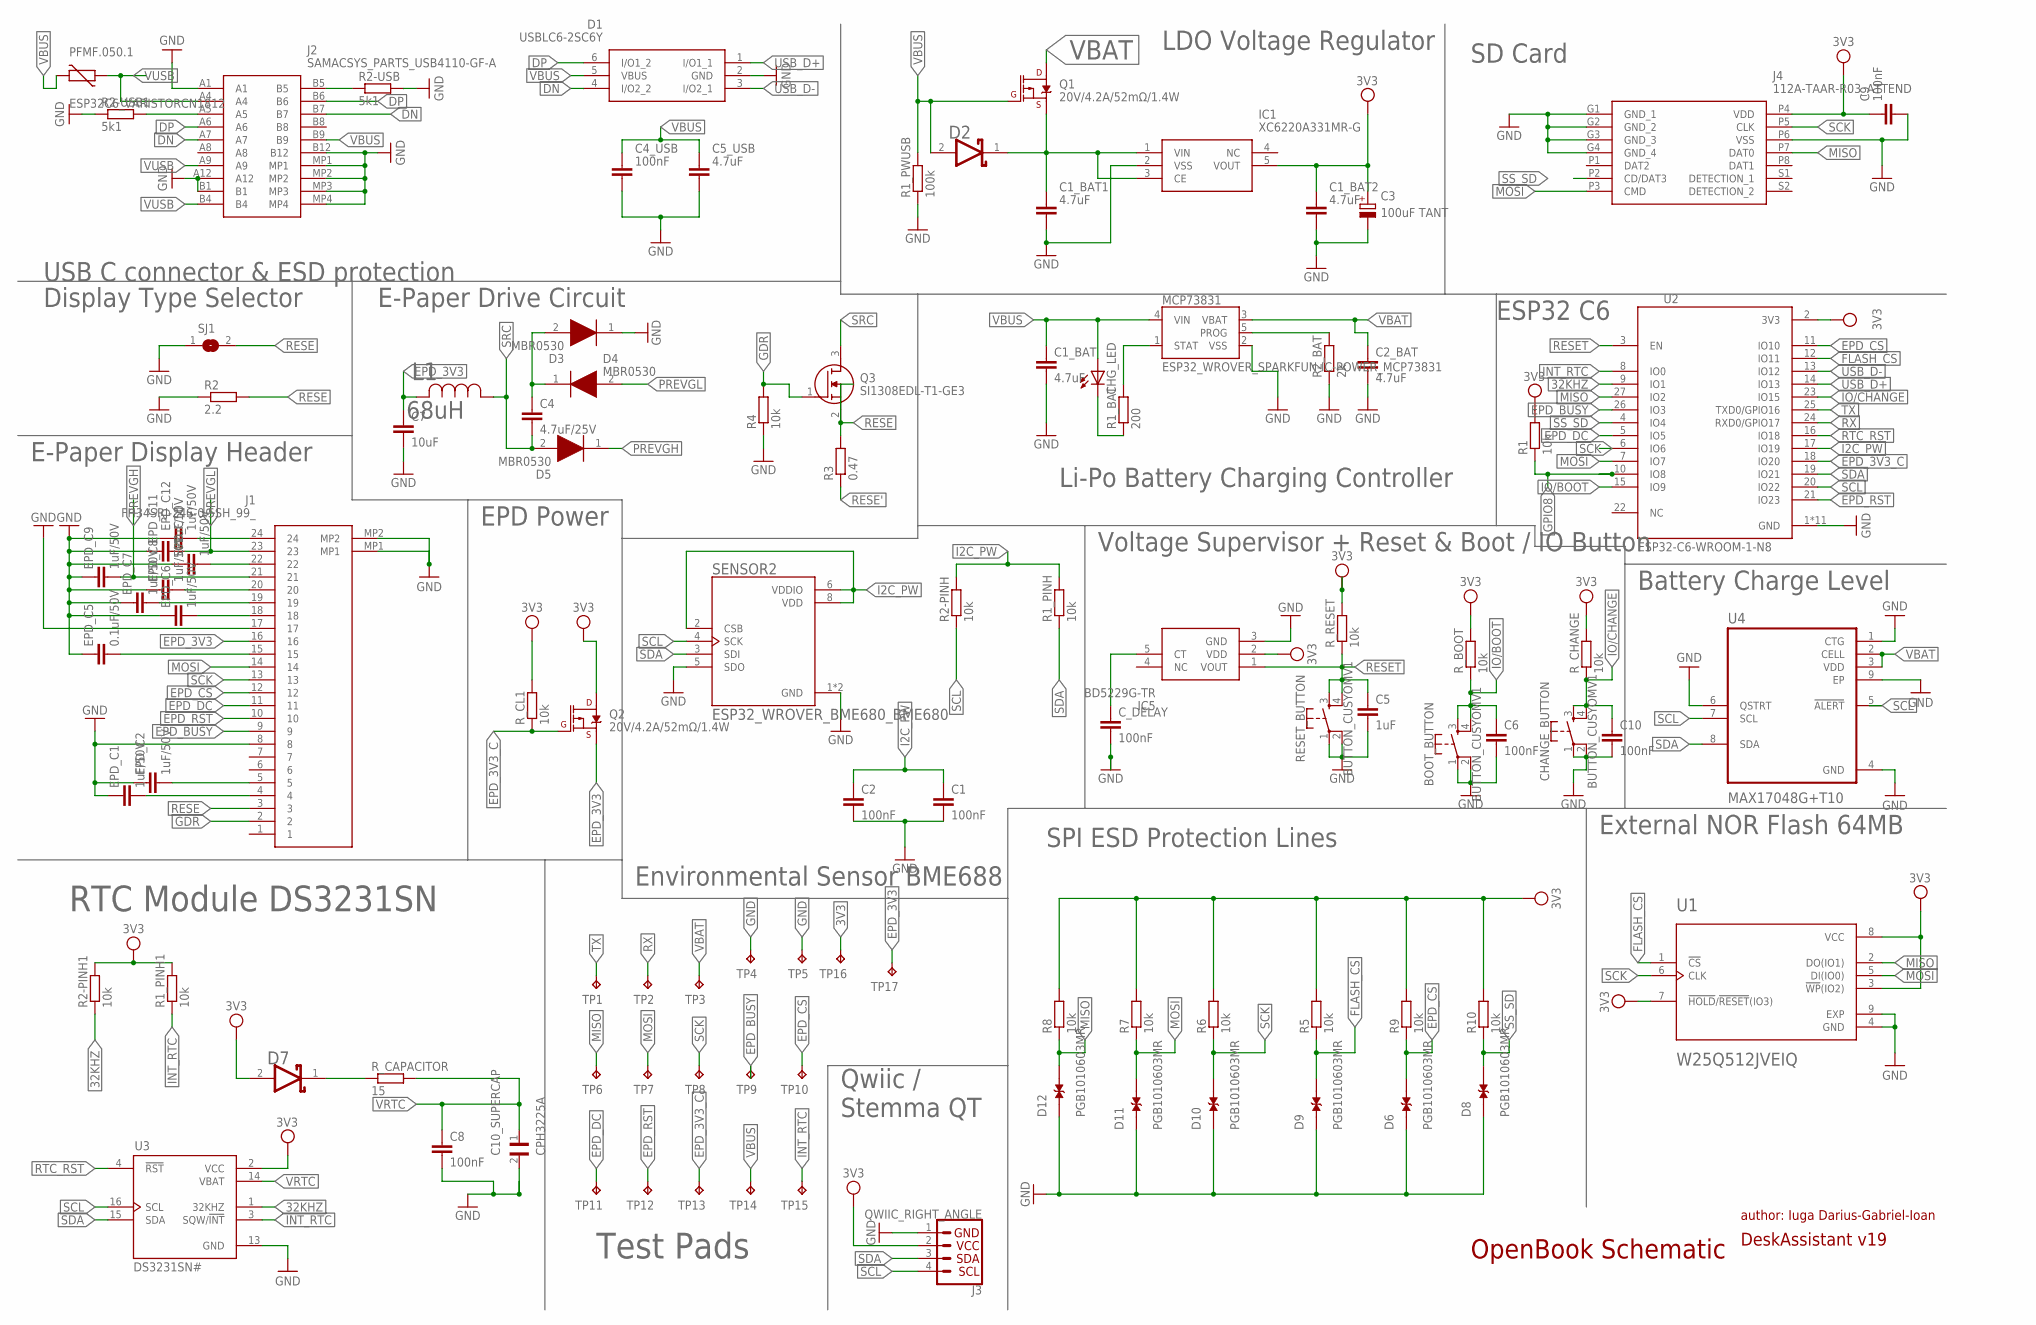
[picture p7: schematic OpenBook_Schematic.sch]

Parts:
BOOT_BUTTON: BUTTON_CUSYOMV1; MYBUTTON
C1, C2, C6, C10: 100nF; ESP32_WROVER_EAGLE-LTSPICE_C0402
C1_BAT, C2_BAT: 4.7uF; ESP32_WROVER_EAGLE-LTSPICE_C0402
C1_BAT1, C5_USB: 4.7uF; CAPC1005X60
C1_BAT2: 4.7uF; CAPM3216X180
C3: 100uF TANT; CAPMP3216X180N
C4: 4.7uF/25V; EAGLE-LTSPICE_C0402
C4_USB, C9: 100nF; CAPC1005X60
C5: 1uF; ESP32_WROVER_EAGLE-LTSPICE_C0402
C7: 10uF; EAGLE-LTSPICE_C0402
C8: 100nF; EAGLE-LTSPICE_C0402
C10_SUPERCAP: CPH3225A; CAPCP3225X100N
CHANGE_BUTTON: BUTTON_CUSYOMV1; MYBUTTON
CHG_LED: ADAFRUIT_LEDCHIP-LED0603; ADAFRUIT_CHIP-LED0603
C_DELAY: 100nF; ESP32_WROVER_EAGLE-LTSPICE_C0402
D1: USBLC6-2SC6Y; SOT95P280X145-6N
D2, D7: ESP32_WROVER_AVX---SD0805S020S1R0_AVX_SD0805S020S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; ESP32_WROVER_AVX---SD0805S020S1R0_AVX_SD0805S020S1R0_0
D3, D4, D5: MBR0530; SOD3716X135N
D6, D8, D9, D10, D11, D12: PGB1010603MR; DIOC1608X36N
EPD_C1, EPD_C2, EPD_C6, EPD_C7, EPD_C8, EPD_C9, EPD_C10, EPD_C11, EPD_C12: 1uF/50V; ESP32_WROVER_EAGLE-LTSPICE_C0402
EPD_C5: 0.1uF/50V; ESP32_WROVER_EAGLE-LTSPICE_C0402
IC1: XC6220A331MR-G; SOT95P280X120-5N
IC5: BD5229G-TR; SOT95P280X125-5N
J1: FH34SRJ-24S-0.5SH_99_; FH34SRJ24S05SH99
J2: SAMACSYS_PARTS_USB4110-GF-A; SAMACSYS_PARTS_USB4110GFA
J3: QWIIC_RIGHT_ANGLE; JST04_1MM_RA
J4: 112A-TAAR-R03_ATTEND; 112ATAARR03ATTEND
L1: 68uH; IND_4828-WE-TPC_WRE
MCP73831: ESP32_WROVER_SPARKFUN-IC-POWER_MCP73831; ESP32_WROVER_SPARKFUN-IC-POWER_SOT23-5
PFMF.050.1: ESP32C6_VARISTORCN1812; ESP32C6_VARISTOR_CT/CN1812
Q1, Q2: 20V/4.2A/52mΩ/1.4W; ESP32_WROVER_SPARKFUN-DISCRETESEMI_SOT23-3
Q3: SI1308EDL-T1-GE3; SOT65P210X110-3N
R1, R1_PINH, R1_PINH1, R2-PINH, R2-PINH1, R4, R5, R6, R7, R8, R9, R10: 10k; ESP32_WROVER_EAGLE-LTSPICE_R0402
R1_BAT: 200; ESP32_WROVER_EAGLE-LTSPICE_R0402
R1_PWUSB: 100k; ESP32_WROVER_EAGLE-LTSPICE_R0402
R2: 2.2; ESP32_WROVER_EAGLE-LTSPICE_R0402
R2-USB, R2-USB1: 5k1; ESP32_WROVER_EAGLE-LTSPICE_R0402
R2_BAT: 2k; ESP32_WROVER_EAGLE-LTSPICE_R0402
R3: 0.47; ESP32_WROVER_EAGLE-LTSPICE_R0402
RESET_BUTTON: BUTTON_CUSYOMV1; MYBUTTON
R_BOOT: 10k; ESP32_WROVER_EAGLE-LTSPICE_R0402
R_CAPACITOR: 15; ESP32_WROVER_EAGLE-LTSPICE_R0402
R_CHANGE: 10k; ESP32_WROVER_EAGLE-LTSPICE_R0402
R_CL1: 10k; ESP32_WROVER_EAGLE-LTSPICE_R0402
R_RESET: 10k; ESP32_WROVER_EAGLE-LTSPICE_R0402
SENSOR2: ESP32_WROVER_BME680_BME680; ESP32_WROVER_BME680_PSON80P300X300X100-8N
SJ1: SJ
TP1, TP2, TP3, TP4, TP5, TP6, TP7, TP8, TP9, TP10, TP11, TP12, TP13, TP14, TP15, TP16, TP17: TPB1,27; B1,27
U1: W25Q512JVEIQ; SON127P600X800X80-9N
U2: ESP32-C6-WROOM-1-N8; XCVR_ESP32-C6-WROOM-1-N8
U3: DS3231SN#; SOIC127P1032X265-16N
U4: MAX17048G+T10; SON50P200X200X80-9N

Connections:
3V3: C1_BAT2.1, C3.1 (+), C9.1, D7.2 (ANODE), IC1.5 (VOUT), IC5.2 (VDD), J3.2, J4.P4 (VDD), Q2.3 (D), R1.2, R1_PINH1.2, R2-PINH1.2, R5.2, R6.2, R7.2, R8.2, R9.2, R10.2, R_BOOT.2, R_CHANGE.2, R_CL1.2, R_RESET.2, TP16.TP, U1.3 (!WP!(IO2)), U1.7 (!HOLD!/!RESET!(IO3)), U1.8 (VCC), U2.2 (3V3), U3.2 (VCC)
32KHZ: R2-PINH1.1, U2.9 (IO1), U3.1 (32KHZ)
DN: D1.4 (I/O2_2), J2.A7, J2.B7
DP: D1.6 (I/O1_2), J2.A6, J2.B6
EPD_3V3: C7.1, J1.16, L1.2, Q2.2 (S), TP17.TP
EPD_3V3_C: Q2.1 (G), R_CL1.1, TP13.TP, U2.18 (IO20)
EPD_BUSY: J1.9, TP9.TP, U2.26 (IO3)
EPD_CS: D6.2, J1.12, R9.1, TP10.TP, U2.11 (IO10)
EPD_DC: J1.11, TP11.TP, U2.5 (IO5)
EPD_RST: J1.10, TP12.TP, U2.21 (IO23)
FLASH_CS: D9.2, R5.1, U1.1 (!CS), U2.12 (IO11)
GDR: J1.2, Q3.1 (G), R4.2
GND: BOOT_BUTTON.1, BOOT_BUTTON.2, C1.2, C1_BAT.2, C1_BAT1.2, C1_BAT2.2, C2.2, C2_BAT.2, C3.2 (-), C4_USB.2, C5.2, C5_USB.2, C6.2, C7.2, C8.2, C9.2, C10.2, C10_SUPERCAP.2, CHANGE_BUTTON.1, CHANGE_BUTTON.2, C_DELAY.2, D1.2 (GND), D3.1 (K), D6.1, D8.1, D9.1, D10.1, D11.1, D12.1, EPD_C1.1, EPD_C2.1, EPD_C5.1, EPD_C6.1, EPD_C7.1, EPD_C8.1, EPD_C9.1, EPD_C10.1, EPD_C11.1, EPD_C12.1, IC1.2 (VSS), IC5.3 (GND), J1.8, J1.17, J1.MP1, J1.MP2, J2.A1, J2.A12, J2.B1, J2.B12, J2.MP1, J2.MP2, J2.MP3, J2.MP4, J3.1, J4.G1 (GND_1), J4.G2 (GND_2), J4.G3 (GND_3), J4.G4 (GND_4), J4.P6 (VSS), MCP73831.2 (VSS), R1_PWUSB.1, R2.1, R2-USB.2, R2-USB1.1, R2_BAT.1, R4.1, RESET_BUTTON.1, RESET_BUTTON.2, SENSOR2.1 (GND), SENSOR2.5 (SDO), SENSOR2.7 (GND), SJ1.1, TP4.TP, TP5.TP, U1.4 (GND), U1.9 (EXP), U2.1 (GND), U2.28 (GND), U2.29_1 (GND), U2.29_2 (GND), U2.29_3 (GND), U2.29_4 (GND), U2.29_5 (GND), U2.29_6 (GND), U2.29_7 (GND), U2.29_8 (GND), U2.29_9 (GND), U3.13 (GND), U4.1 (CTG), U4.4 (GND), U4.6 (QSTRT), U4.9 (EP)
GPIO8: R1.1, U2.10 (IO8)
I2C_PW: C1.1, C2.1, R1_PINH.2, R2-PINH.2, SENSOR2.2 (CSB), SENSOR2.6 (VDDIO), SENSOR2.8 (VDD), U2.17 (IO19)
INT_RTC: R1_PINH1.1, TP15.TP, U2.8 (IO0), U3.3 (SQW/!INT)
IO/BOOT: BOOT_BUTTON.3, BOOT_BUTTON.4, C6.1, R_BOOT.1, U2.15 (IO9)
IO/CHANGE: C10.1, CHANGE_BUTTON.3, CHANGE_BUTTON.4, R_CHANGE.1, U2.23 (IO15)
MISO: D12.2, J4.P7 (DAT0), R8.1, TP6.TP, U1.2 (DO(IO1)), U2.27 (IO2)
MOSI: D11.2, J1.14, J4.P3 (CMD), R7.1, TP7.TP, U1.5 (DI(IO0)), U2.7 (IO7)
unnamed: C1_BAT1.1, D2.1 (CATHODE), IC1.1 (VIN), IC1.3 (CE), Q1.2 (S)
unnamed: J2.A5, R2-USB1.2
unnamed: C4.1, D3.2 (A), D4.1 (K)
unnamed: MCP73831.5 (PROG), R2_BAT.2
unnamed: MCP73831.1 (STAT), R1_BAT.2
unnamed: CHG_LED.C, R1_BAT.1
unnamed: EPD_C1.2, J1.4
unnamed: EPD_C2.2, J1.5
unnamed: EPD_C5.2, J1.15
unnamed: EPD_C6.2, J1.18
unnamed: EPD_C7.2, J1.19
unnamed: EPD_C8.2, J1.20
unnamed: C_DELAY.1, IC5.5 (CT)
unnamed: EPD_C10.2, J1.22
unnamed: D7.1 (CATHODE), R_CAPACITOR.1
unnamed: EPD_C12.2, J1.24
unnamed: J2.B5, R2-USB.1
PREVGH: D5.1 (K), EPD_C9.2, J1.21
PREVGL: D4.2 (A), EPD_C11.2, J1.23
RESE: J1.3, Q3.2 (S), R2.2, R3.2, SJ1.2
RESE': R3.1
RESET: C5.1, IC5.1 (VOUT), RESET_BUTTON.3, RESET_BUTTON.4, R_RESET.1, U2.3 (EN)
RTC_RST: U2.16 (IO18), U3.4 (!RST)
RX: TP2.TP, U2.24 (RXD0/GPIO17)
SCK: D10.2, J1.13, J4.P5 (CLK), R6.1, TP8.TP, U1.6 (CLK), U2.6 (IO6)
SCL: J3.4, R2-PINH.1, SENSOR2.4 (SCK), U2.20 (IO22), U3.16 (SCL), U4.5 (!ALERT), U4.7 (SCL)
SDA: J3.3, R1_PINH.1, SENSOR2.3 (SDI), U2.19 (IO21), U3.15 (SDA), U4.8 (SDA)
SRC: C4.2, D5.2 (A), L1.1, Q3.3 (D)
SS_SD: D8.2, J4.P2 (CD/DAT3), R10.1, U2.4 (IO4)
TX: TP1.TP, U2.25 (TXD0/GPIO16)
USB_D+: D1.1 (I/O1_1), U2.14 (IO13)
USB_D-: D1.3 (I/O2_1), U2.13 (IO12)
VBAT: C2_BAT.1, MCP73831.3 (VBAT), Q1.3 (D), TP3.TP, U4.2 (CELL), U4.3 (VDD)
VBUS: C1_BAT.1, C4_USB.1, C5_USB.1, CHG_LED.A, D1.5 (VBUS), D2.2 (ANODE), J2.B9, MCP73831.4 (VIN), PFMF.050.1.2, Q1.1 (G), R1_PWUSB.2, TP14.TP
VRTC: C8.1, C10_SUPERCAP.1, R_CAPACITOR.2, U3.14 (VBAT)
VUSB: J2.A4, J2.A9, J2.B4, PFMF.050.1.1

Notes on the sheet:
SD Card
USB C connector & ESD protection
LDO Voltage Regulator
ESP32 C6
Li-Po Battery Charging Controller
E-Paper Drive Circuit
Display Type Selector
E-Paper Display Header
EPD Power
Environmental Sensor BME688
Voltage Supervisor + Reset & Boot / IO Button
Battery Charge Level
External NOR Flash 64MB
SPI ESD Protection Lines
Qwiic / Stemma QT
Test Pads
RTC Module DS3231SN
OpenBook Schematic
author: Iuga Darius-Gabriel-Ioan
DeskAssistant v19

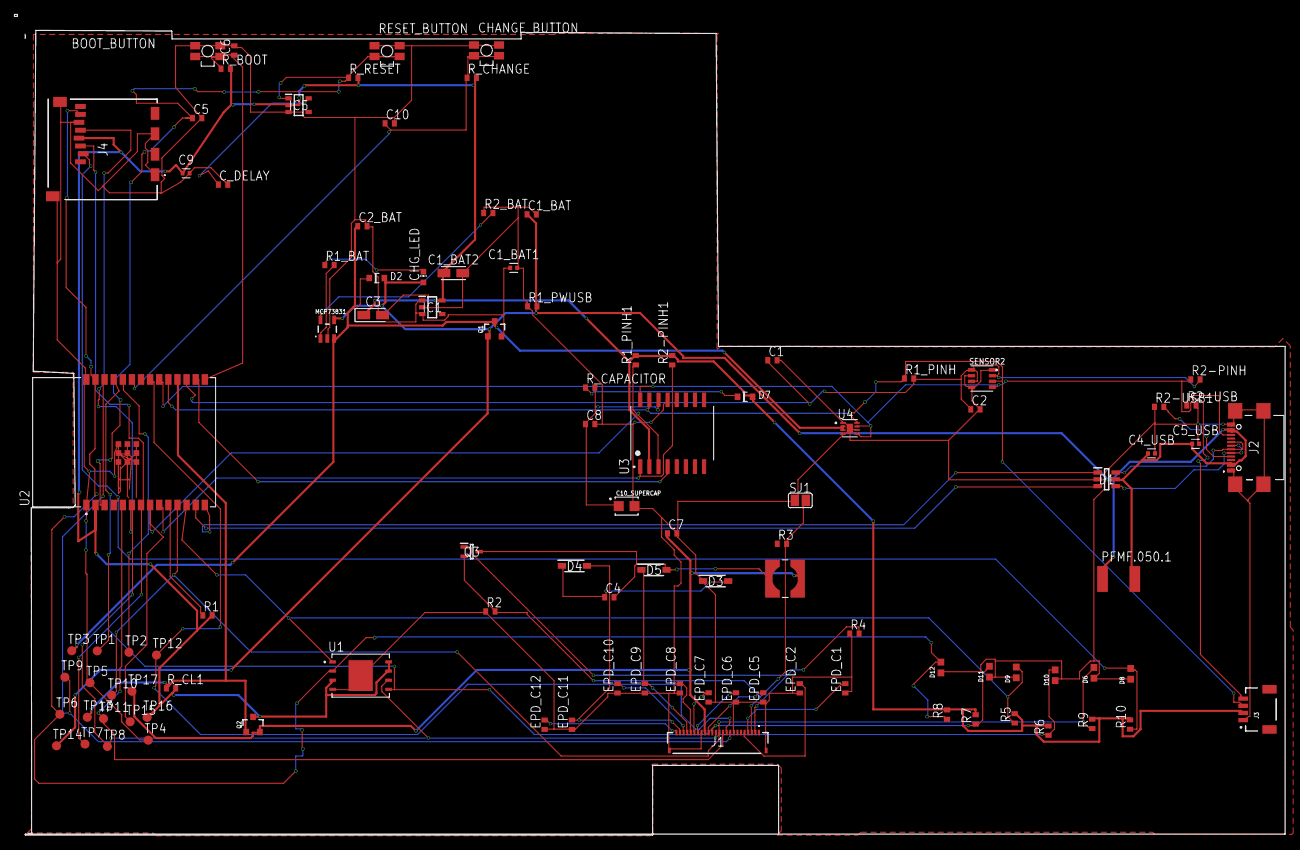
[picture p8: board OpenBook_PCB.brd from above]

Board: 2 copper layers, 177.1 x 114.4 mm, 103 parts (0 on the bottom side), 55 nets.

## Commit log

2025-04-06 Add electronics files
    [BOM_OpenBook_PCB v3.csv, OpenBook_PCB.brd, OpenBook_Schematic.sch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]
2025-04-06 Am adaugat descrierea hardware si a functionalitatii pin-urilor
2025-04-06 Add bom to readme
2025-04-14 Fix schematic warnings (fixes #2, fixes #3, fixes #4, fixes #5)
    [OpenBook_Schematic.sch]
2025-04-14 Moved PCB dimensions from layer Top to layer Dimensions (fixes #8)
    [OpenBook_PCB.brd]
2025-04-15 Added cutout for PCB near buttons (fixes #7)
    [OpenBook_PCB.brd]

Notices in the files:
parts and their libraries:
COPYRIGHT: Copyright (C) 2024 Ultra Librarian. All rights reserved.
